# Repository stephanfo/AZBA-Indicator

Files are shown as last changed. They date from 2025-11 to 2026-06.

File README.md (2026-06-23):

# AZBA Status Indicator

A 3D-printable WiFi-connected LED indicator display for real-time monitoring of AZBA (Airspace Restriction Zone) activation status. This project displays the current and upcoming airspace restrictions for a configurable zone using an ESP8266 microcontroller and addressable RGB LEDs.

**Hardware Model:** [AZBA Status Indicator on Printables](https://www.printables.com/model/1487021-azba-status-indicator-3d-printable-display-for-des)

<div align="center">

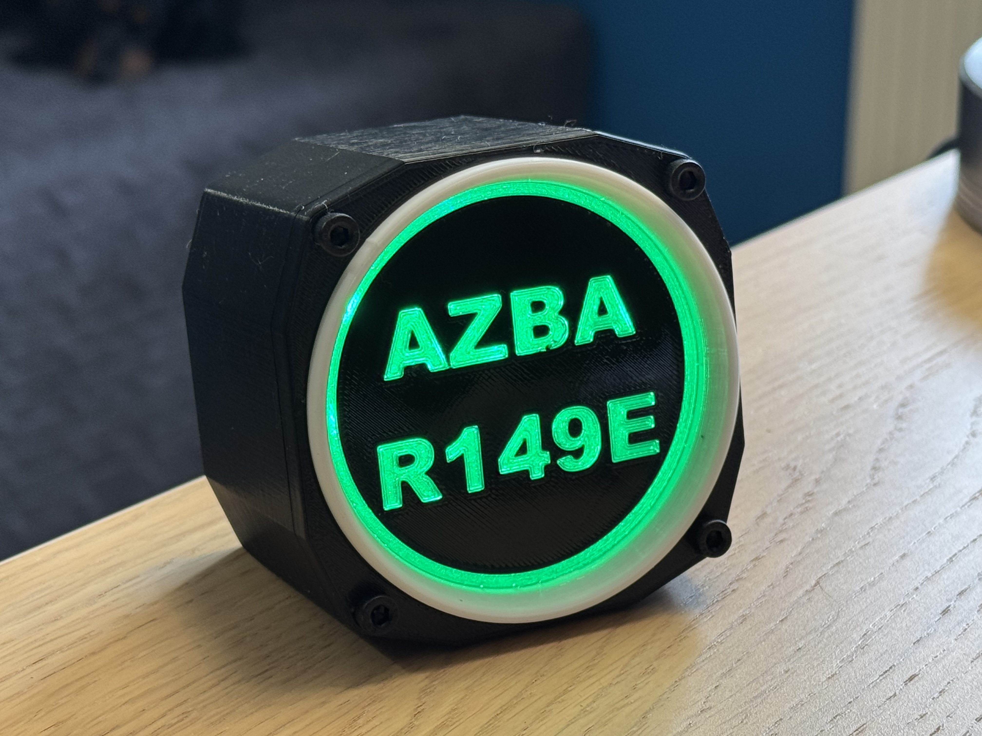
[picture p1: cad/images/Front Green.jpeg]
Front View

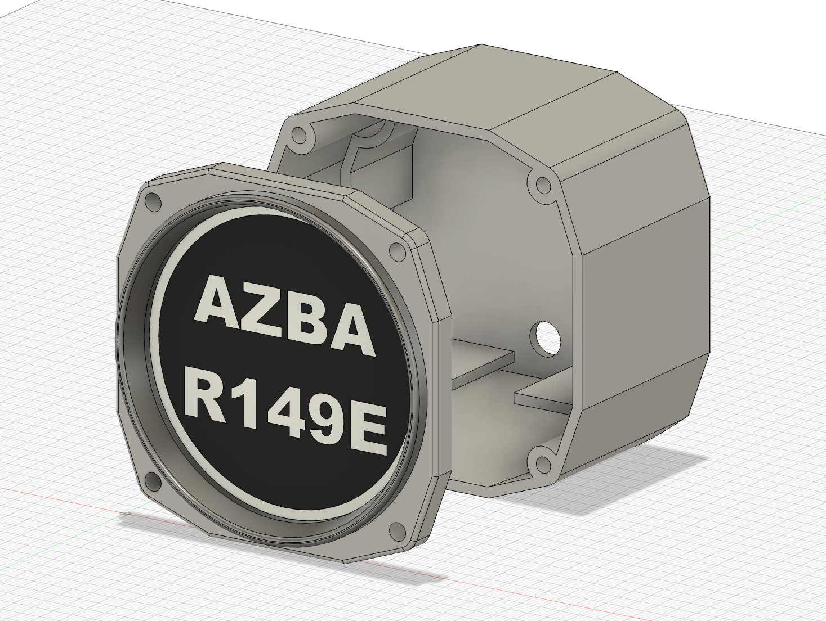
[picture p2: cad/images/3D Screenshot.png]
3D Model

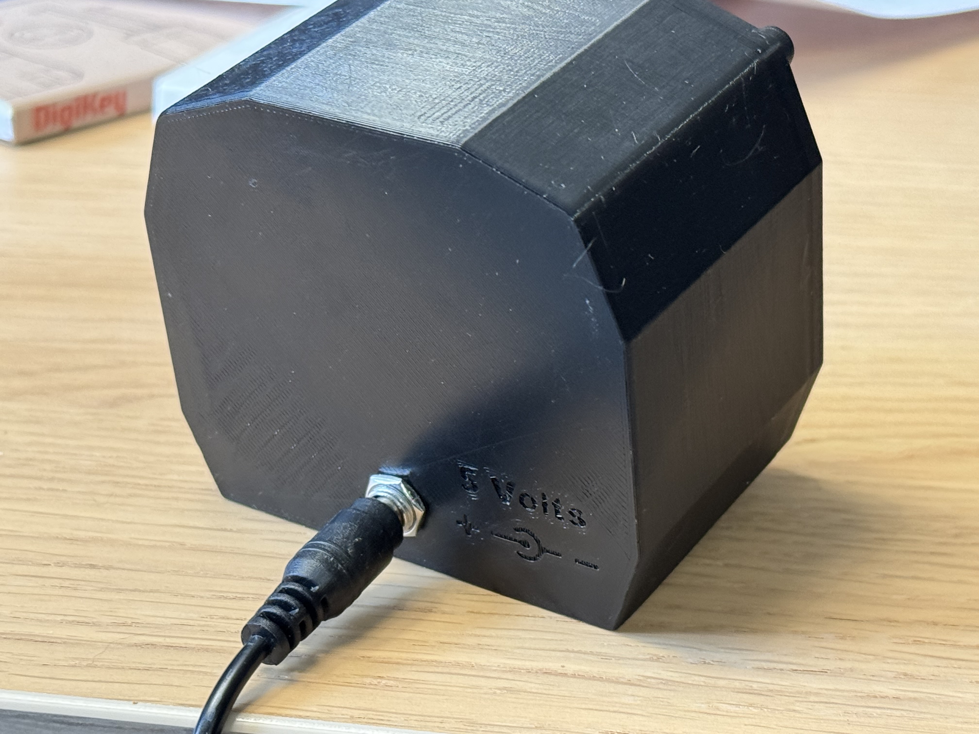
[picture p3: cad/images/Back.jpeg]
Back View

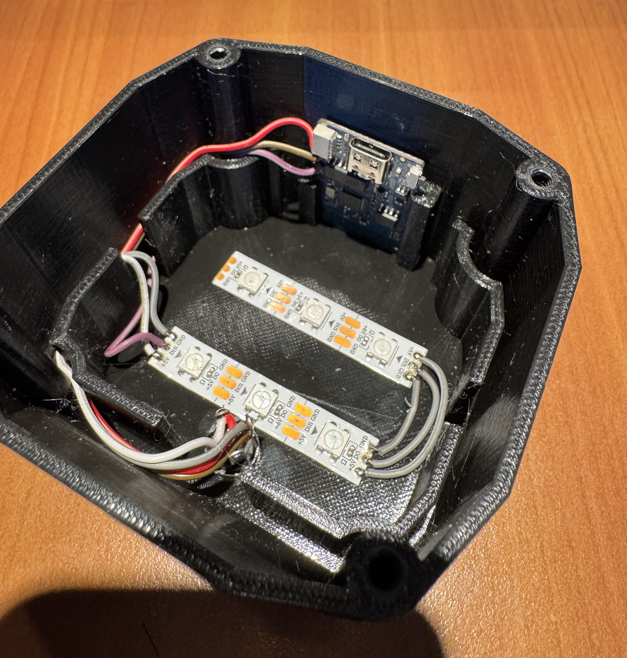
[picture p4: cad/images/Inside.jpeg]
Inside View


</div>

## Features

- **Real-time AZBA Status Display** — Shows if your configured airspace zone is currently active
- **Upcoming Activity Alerts** — Visual indication if the zone will be active within 4 hours
- **LED Status Indicators**
  - 🟢 Green (solid): Zone inactive and not planned to be active
  - 🟡 Yellow (solid): Zone will be active in the future
  - 🟠 Orange (blinking): Zone will be active soon (within 4 hours)
  - 🔴 Red (blinking): Zone active now
  - 🔵 Blue: WiFi connecting
  - ⚪ White: Error or startup
- 🔄 **Automatic Refresh** — Fetches AZBA data every 5 minutes
- 🔁 **Auto-Reboot** — Automatically reboots every 48 hours to prevent memory drift
- 🛡️ **WiFi Resilience** — Automatic retry logic (3 retries with 25-second intervals)
- 🌐 **Static or DHCP IP** — Flexible network configuration

## Hardware Requirements

- **Microcontroller:** Wemos D1 Mini Lite (ESP8266)
- **LEDs:** 6× WS2812B (NeoPixel) addressable RGB LEDs
- **Power Supply:** 5V/1A jack
- **3D Enclosure:** See [Printables model](https://www.printables.com/model/1487021-azba-status-indicator-3d-printable-display-for-des)

## Software Requirements

- **PlatformIO** (recommended) or Arduino IDE
- **Python 3** (optional - for generating secrets from environment variables)
- **PHP 8.0+** with cURL (for the `php/azba.php` backend and its tests; no Composer needed)
- **Dependencies** (auto-installed by PlatformIO):
  - Adafruit NeoPixel library
  - ArduinoJson library

## Quick Start

### 1. Clone the Repository

```bash
git clone https://github.com/stephanfo/AZBA-Indicator.git
cd AZBA-Indicator
```

### 2. Configure Your Secrets

Copy the example secrets file:

```bash
cp src/secrets.example.h src/secrets.h
```

Edit `src/secrets.h` with your WiFi credentials:

```c
const char* ssid     = "Your-WiFi-SSID";
const char* password = "Your-WiFi-Password";
```

**Or** use environment variables for automated generation:

```bash
export SSID="Your-WiFi-SSID"
export PASSWORD="Your-WiFi-Password"
```

### 3. Configure Your AZBA Zone

Edit `src/main.cpp` and change the `ZONE_ID` to your desired zone:

```cpp
const char* ZONE_ID  = "R149E";   // Change to your zone (e.g., R45S3, R142A)
```

Available zones: R45S3, R142A, R45N5.1, R45N4, etc. (see AZBA documentation)

### 4. Build and Upload

```bash
platformio run
platformio run --target upload
```

Or use the pre-configured tasks in VS Code if you have PlatformIO extension installed.

### 5. Monitor Serial Output

```bash
platformio device monitor --baud 115200
```

## Advanced Configuration

### Static IP (Optional)

If you want to use a static IP instead of DHCP, set environment variables before building:

```bash
export SSID="Your-WiFi-SSID"
export PASSWORD="Your-WiFi-Password"
export USE_STATIC_IP=true
export STATIC_IP="192.168.1.50"
export GATEWAY_IP="192.168.1.1"
export SUBNET_MASK="255.255.255.0"
export DNS1_IP="8.8.8.8"
export DNS2_IP="8.8.4.4"
platformio run
```

Then uncomment `#define USE_STATIC_IP` in `src/secrets.h` if not auto-generated.

### Configurable Parameters

Edit the constants in `src/main.cpp`:

- `FETCH_INTERVAL_MS` — Refresh interval (default: 300,000 ms = 5 minutes)
- `REBOOT_INTERVAL_MS` — Auto-reboot interval (default: 172,800,000 ms = 48 hours)
- `FETCH_MAX_RETRIES` — Number of retries on failure (default: 3)
- `FETCH_RETRY_INTERVAL_MS` — Delay between retries (default: 25 seconds)
- `LED_PIN` — GPIO pin for LED strip (default: D4)
- `LED_COUNT` — Number of LEDs (default: 6)

## LED Behavior

### Status Modes

| Mode | LED Color | Behavior | Meaning |
|---|---|---|---|
| `MODE_INACTIVE` | Green | Solid | Zone is inactive |
| `MODE_WILL_BE_ACTIVE_LATER` | Yellow | Solid | Zone will be active, but beyond 4 hours |
| `MODE_WILL_BE_ACTIVE_SOON` | Orange | Blinking | Zone will be active within 4 hours |
| `MODE_ACTIVE_NOW` | Red | Blinking | Zone is active right now |
| `MODE_CONNECTING` | Blue | Solid | WiFi is connecting |
| `MODE_ERROR_OR_STARTUP` | White | Solid | Startup or error condition |

## API Data Source

The device does **not** talk to the SIA directly. It calls a small PHP backend
(`php/azba.php`) that you host on your own server or public endpoint; the
firmware fetches `azba.php?azba=<ZONE_ID>` and reads three booleans per zone
(`is_active_now`, `will_be_active`, `will_be_active_soon`).

The backend is split into two files along a clean reuse boundary:

- **`php/azba_lib.php`** — a self-contained, reusable SIA client. It queries the
  **official SIA JSON API** (the same backend the "AZBA2" web app at
  `https://www.sia.aviation-civile.gouv.fr/azbaEx/` uses), decodes it, and
  validates it (fail-safe guards). It returns the **raw extracted data only** —
  the validity interval and each zone's activation time slots:
  - `…/api/v3/custom/currentDate` — the current validity window
  - `…/api/v3/r_t_b_as?…` — the list of active zones with their UTC time slots
- **`php/azba.php`** — the project-specific request handler. It holds this
  product's application logic: the activity flags (`is_active_now` /
  `will_be_active` / `will_be_active_soon`, with the +5 min anticipation and the
  4-hour window), the `?azba=<ZONE_ID>` filter, the metadata counters, and the
  JSON output contract the firmware expects.

> Historically `azba.php` scraped the HTML of `/schedules`. That page is now a
> JavaScript single-page app with no parseable text, so the scraper broke. The
> backend was rewritten to use the structured JSON API above, which is far more
> robust to wording/markup changes. See [CHANGELOG.md](CHANGELOG.md).

### Reusing the library in another project

`php/azba_lib.php` has no dependencies (no Composer). Copy it in, `require` it,
and call `azba_fetch()` to get the raw SIA data; then apply whatever analysis and
output format your project needs. You only write your own handler — never the
SIA querying/extraction.

```php
require 'azba_lib.php';

try {
    $sia = azba_fetch();
    // $sia = [
    //   'interval' => ['start_utc' => '...Z', 'end_utc' => '...Z'],
    //   'zones'    => [ 'R45S3' => ['activations' => [
    //       ['date' => 'YYYY-MM-DD', 'start_utc' => '...Z', 'end_utc' => '...Z'], ...
    //   ]], ... ],   // only zones active in the current window are present
    // ];

    // ...your project's logic: decide what "active/soon" means, format, etc.
    echo json_encode($sia);
} catch (AzbaFetchException $e) {  // SIA unreachable / auth rejected (HTTP code in getCode())
    // handle network failure
} catch (AzbaDataException $e) {   // SIA responded but the data can't be trusted
    // handle contract change — fail visibly, never assume "inactive"
}
```

See `php/azba.php` for a complete handler that turns this raw data into the
firmware's activity flags + JSON. Its `azba_compute_flags()` / `azba_filter_zone()`
/ `azba_build_metadata()` are examples of the per-project layer you would adapt.

To override the API base or shared secret (e.g. after a SIA rotation) without
editing the file, `define('AZBA_API_BASE', …)` / `define('AZBA_SHARE_SECRET', …)`
before the `require`, or pass `apiBase` / `shareSecret` in the `azba_fetch()`
options array.

### Fail-safe design (important)

A *false "inactive"* is dangerous — it could imply a restricted low-altitude
military zone is clear when it is actually active. So `azba.php` **never returns
a "200 OK" it is not confident in**: on any doubt (auth rejected, unexpected
response shape, stale validity window, unparsable times) it returns an HTTP
error, which the firmware shows as the **white ERROR LED** (a visible fault)
rather than silently signalling "clear" (green).

### Backend maintenance & tests

The data-integrity guards and the time logic are unit-tested. From the repo root:

```bash
php tests/run.php              # offline, deterministic unit tests
AZBA_LIVE=1 php tests/run.php  # also checks the live SIA API contract
```

If the SIA rotates its API again, the live test fails fast and the header of
`php/azba_lib.php` documents how to re-extract the API base / shared secret from
the web app bundle.

## Project Structure

```
.
├── README.md                      # This file
├── CHANGELOG.md                   # Notable changes per version
├── platformio.ini                 # PlatformIO configuration
├── src/
│   ├── main.cpp                   # Main firmware code
│   ├── secrets.example.h          # Template for WiFi credentials & IP config
│   └── secrets.h                  # ⚠️ Local credentials (NOT committed, git-ignored)
├── extra/
│   └── generate_secrets.py        # Script to auto-generate secrets.h from env vars
├── php/
│   ├── azba.php                   # Example request handler (reads ?azba=, outputs JSON)
│   └── azba_lib.php               # Self-contained, reusable SIA client (azba_fetch)
├── tests/
│   ├── run.php                    # Zero-dependency test runner (php tests/run.php)
│   └── fixtures/                  # Captured SIA API responses for offline tests
├── cad/
│   ├── fusion360/                 # 3D CAD files (Fusion 360 project)
│   ├── step/                      # STEP format 3D models
│   └── images/                    # Product photos and 3D renderings
└── .gitignore                     # Git ignore rules (includes secrets, build artifacts)
```

## Building the 3D Enclosure

The 3D printable enclosure is available on Printables:
[AZBA Status Indicator Model](https://www.printables.com/model/1487021-azba-status-indicator-3d-printable-display-for-des)

**Recommended Settings:**
- **Material:** PLA or PETG
- **Layer Height:** 0.2 mm
- **Infill:** 15–20%
- **Support:** Yes (for LED window)
- **Print Time:** ~4–6 hours
- **Filament:** ~40–50 grams

## Troubleshooting

### Device won't connect to WiFi

1. Check credentials in `src/secrets.h`
2. Verify SSID is not hidden
3. Ensure WiFi signal is strong and 2.4GHz available
4. Check serial output for error messages: `platformio device monitor --baud 115200`

### LEDs not lighting up

1. Verify LED_PIN configuration matches your wiring (default: D4)
2. Check power supply (5V, adequate amperage for all LEDs)
3. Verify WS2812B LED strip is properly connected (GND, 5V, Data)
4. Try uploading LED test sketch to verify wiring

### AZBA data not updating

1. Check internet connection: Open serial monitor and look for HTTP errors
2. Verify `ZONE_ID` is valid
3. Ensure backend URL (`URL_BASE`) is accessible
4. If the LED is **white (error)**, the backend returned a non-200 — this is the
   intended fail-safe (never a false "inactive"). Hit `azba.php` directly in a
   browser to read the JSON `error` message.
5. Run `AZBA_LIVE=1 php tests/run.php` on the server: if the live test fails, the
   SIA API contract changed and `php/azba.php` needs updating (the file header
   documents how to re-extract the API base / shared secret).

### Device reboots frequently

1. Check power supply stability (use good quality PSU)
2. Verify antenna position on Wemos D1 Mini (avoid metal surfaces around)
3. Increase `REBOOT_INTERVAL_MS` if reboots are too frequent

## Contributing

Contributions are welcome! Please:

1. Fork the repository
2. Create a feature branch (`git checkout -b feature/your-feature`)
3. Make your changes
4. Test thoroughly on hardware
5. Commit with clear messages
6. Push to your fork
7. Open a Pull Request

## License

This project is licensed under the MIT License — see LICENSE file for details.

## Support & Feedback

- **Issues:** [GitHub Issues](https://github.com/stephanfo/AZBA-Indicator/issues)
- **Printables Model Comments:** [Printables Discussion](https://www.printables.com/model/1487021-azba-status-indicator-3d-printable-display-for-des)

## Acknowledgments

- [Adafruit NeoPixel Library](https://github.com/adafruit/Adafruit_NeoPixel)
- [ArduinoJson Library](https://github.com/bblanchon/ArduinoJson)
- [PlatformIO](https://platformio.org/)
- SIA (Service de l'Information Aéronautique) for AZBA data
- Printables community for hardware feedback

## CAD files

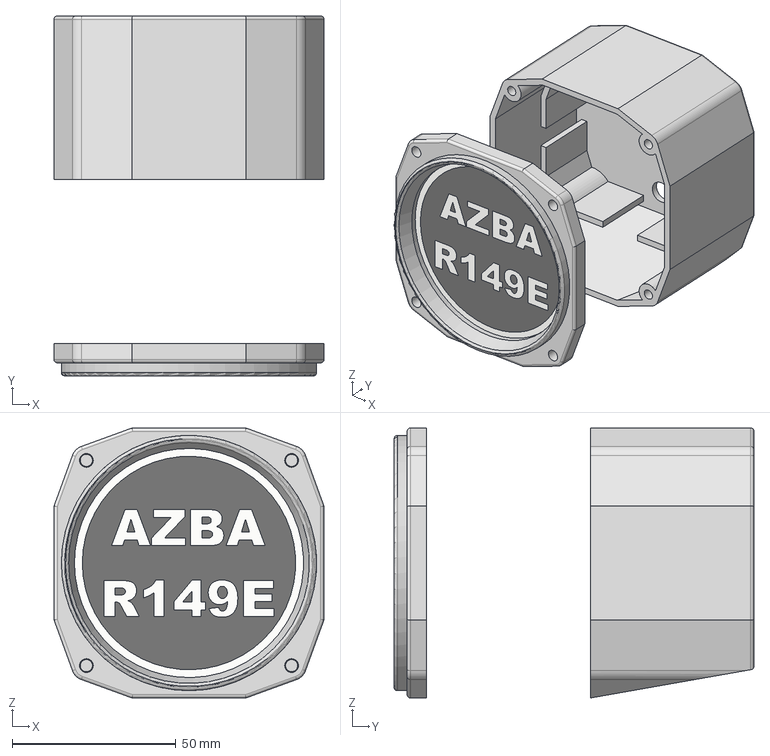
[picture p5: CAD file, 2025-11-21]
cad/step/AZBA R149 Indicator.step
82.5 x 110.0 x 82.5 mm

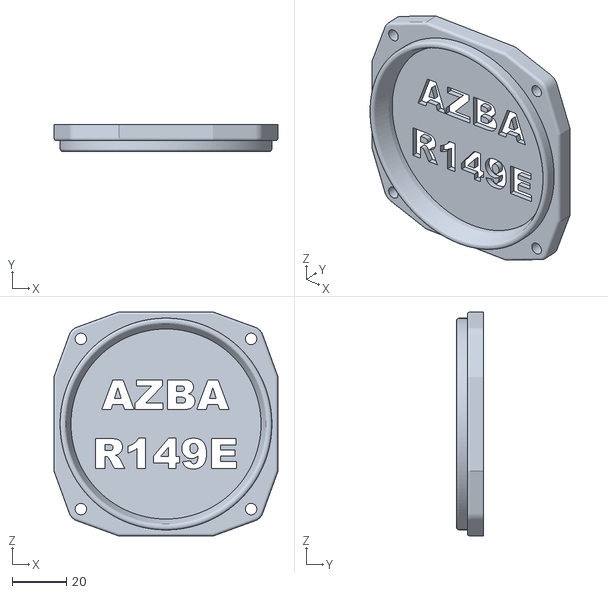
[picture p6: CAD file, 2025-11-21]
cad/stl/Front - Monochrome no MMU.stl
82.5 x 10.0 x 82.5

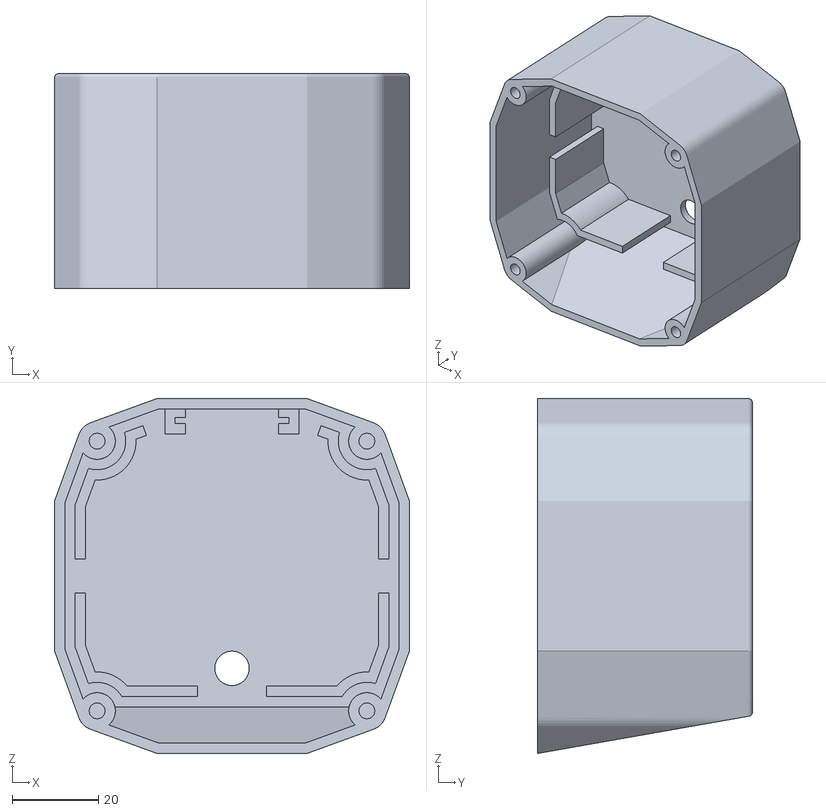
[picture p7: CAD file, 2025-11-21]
cad/stl/Back Case.stl
82.5 x 50.0 x 82.5

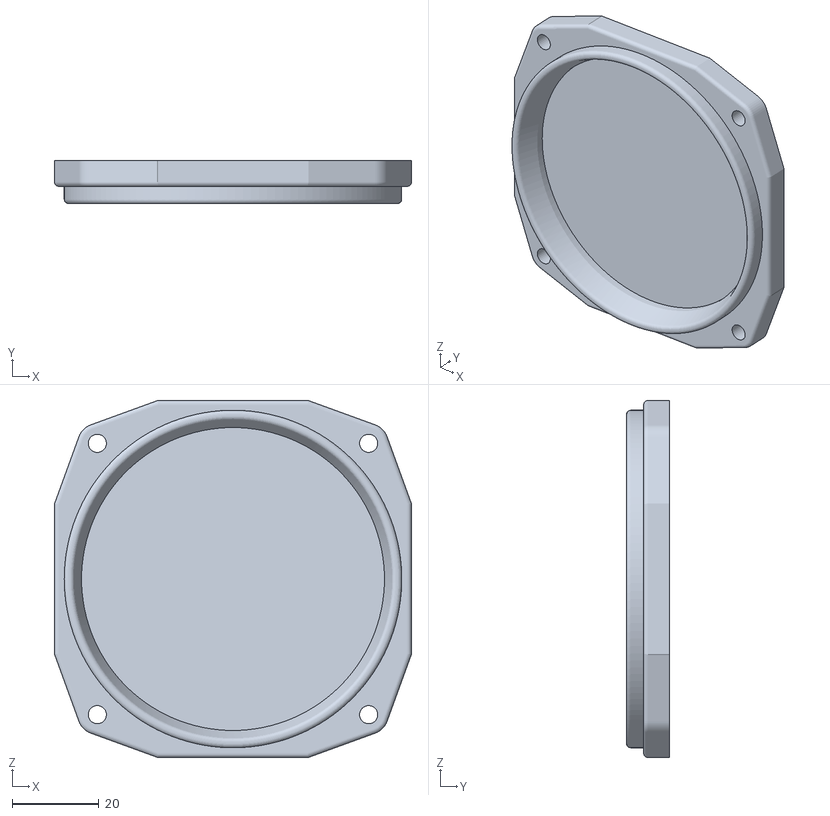
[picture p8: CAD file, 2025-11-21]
cad/stl/Front - MMU2S.stl
82.5 x 10.0 x 82.5

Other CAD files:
cad/fusion360/AZBA R149 Indicator.f3d

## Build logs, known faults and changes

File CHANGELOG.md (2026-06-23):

# Changelog

All notable changes to this project are documented here.

The format is based on [Keep a Changelog](https://keepachangelog.com/en/1.1.0/).
This project does not yet use formal version tags; entries are grouped by date.

## [Unreleased]

### Changed
- **`php/azba.php` rewritten to use the official SIA JSON API.** The old version
  scraped the HTML of `/schedules` and searched for the text
  `"Liste des zones activées"`. The SIA replaced that page with a JavaScript
  single-page app ("AZBA2"), so the text disappeared and the script failed with
  `Bloc "Liste des zones activées" introuvable`. It now queries the structured
  endpoints the web app itself uses (`/api/v3/custom/currentDate` and
  `/api/v3/r_t_b_as`), which are immune to wording/markup changes. The JSON
  output contract is unchanged, so **no firmware change is required**.
- Split the backend into `php/azba.php` (thin entry: network + request/response)
  and `php/azba_lib.php` (pure, testable logic) so the safety guards and time
  math can be unit-tested deterministically. Output is byte-for-byte identical.
- **`php/azba_lib.php` is now a self-contained, reusable SIA library** with a
  clean boundary: it does the SIA querying + decoding + extraction only, exposed
  as a single `azba_fetch()` call returning the **raw data**
  (`['interval' => …, 'zones' => [ 'R45S3' => ['activations' => […]], … ]]`).
  All product-specific analysis — the activity flags (`is_active_now` /
  `will_be_active` / `will_be_active_soon`, the +5 min anticipation and 4-hour
  window), the `?azba=` filter, and the metadata counters — moved **into**
  `php/azba.php`, which is now the swappable request handler. Other projects copy
  `azba_lib.php` (no Composer), call `azba_fetch()`, and apply their own logic.
  The HTTP transport is injectable (`$options['http']`) so the full pipeline is
  testable offline, and the API base / shared secret are overridable via
  `define()` or `$options`. Firmware JSON output remains byte-for-byte identical.
- Errors now use a typed hierarchy: `AzbaException` (base), `AzbaFetchException`
  (network / HTTP / auth, with the HTTP status in `getCode()`), and
  `AzbaDataException` (untrusted data). Callers catch `AzbaException` to handle
  all failures and map them to their own response.

### Added
- **Fail-safe data guards.** A false "inactive" is dangerous (it could imply an
  active restricted zone is clear). The backend now returns a non-200 — surfaced
  as the firmware's white ERROR LED — on any untrusted condition: rejected auth,
  unexpected response shape, missing/empty time slots, unparsable times, or a
  stale/inconsistent validity window. It never emits a "200 OK" it isn't
  confident in.
- Single retry on transient 5xx / network errors when fetching active zones.
- **Zero-dependency PHP test battery** (`tests/run.php`, no Composer/PHPUnit):
  covers every fail-safe guard, the validity-window freshness checks, the
  `is_active_now` / `will_be_active` / `will_be_active_soon` boundary math, the
  zone filter, and metadata counters. An opt-in live mode
  (`AZBA_LIVE=1 php tests/run.php`) re-checks the upstream SIA contract so an API
  change is caught early. Offline fixtures live in `tests/fixtures/`.
- Documentation in the `php/azba.php` header explaining the API, the `AUTH`
  header scheme, and how to re-extract the API base / shared secret from the SIA
  web app bundle if the SIA rotates them.

### Fixed
- Indicator no longer fails permanently after the SIA AZBA page redesign.

## [2026-06-23] — Documentation & configuration

### Changed
- Improved LED state descriptions, added the AZBA zone configuration to
  `secrets.example.h`, and updated the base URL.

## [2025-11-22]

### Changed
- `refreshCount` starts at 1 and is incremented even when no AZBA zones are
  found; added the "inside" product image.

## [2025-11-21] — Initial release

### Added
- ESP8266 firmware driving WS2812B LEDs to show AZBA zone status (active now /
  soon / later / inactive), with WiFi resilience and periodic auto-reboot.
- PHP backend, 3D-printable enclosure, and secrets tooling. Default zone aligned
  to `R149E` to match the reference hardware.

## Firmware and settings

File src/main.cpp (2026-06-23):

#include <ESP8266WiFi.h>
#include <ESP8266HTTPClient.h>

#include <Adafruit_NeoPixel.h>
#include <ArduinoJson.h>

#include "secrets.h" // WiFi credentials and optional static IP configuration

// ------------ CONFIG LEDS ------------
#define LED_PIN    D4
#define LED_COUNT  6

Adafruit_NeoPixel strip(LED_COUNT, LED_PIN, NEO_GRB + NEO_KHZ800);

enum Mode {
  MODE_CONNECTING,            // Blue solid (WiFi connecting)
  MODE_ERROR_OR_STARTUP,      // White solid (error/startup)
  MODE_ACTIVE_NOW,            // Red blinking (active now)
  MODE_WILL_BE_ACTIVE_SOON,   // Orange blinking (active soon, within 4h)
  MODE_WILL_BE_ACTIVE_LATER,  // Yellow solid (active later, beyond 4h)
  MODE_INACTIVE               // Green solid (inactive)
};

Mode currentMode = MODE_ERROR_OR_STARTUP;

// --- Intervals and parameters ---
// Interval between normal refreshes (5 minutes)
const unsigned long FETCH_INTERVAL_MS = 300000UL;      // 5 minutes
// Automatic reboot every 48 hours to avoid memory leaks/drift
const unsigned long REBOOT_INTERVAL_MS = 172800000UL;  // 48 hours in milliseconds
// Retry parameters: number of retries and delay between them
// (e.g. FETCH_MAX_RETRIES = 2 => initial attempt + 2 retries)
const int FETCH_MAX_RETRIES = 3;                       // number of retries (0 = no retry)
const unsigned long FETCH_RETRY_INTERVAL_MS = 25000UL; // 25 seconds between retries

// Timestamps and counters
unsigned long lastFetchMs = 0;   // timestamp of last fetch (millis())
unsigned long startupTimeMs = 0; // application startup timestamp
// Number of refresh cycles performed (incremented before each fetch)
// This counter is sent to the server for diagnostics (`refresh_count`)
unsigned long refreshCount = 1; // number of refreshes (5-minute cycles)
// Diagnostics counters
unsigned long totalAttempts = 0;          // total HTTP attempts across retries
unsigned long totalSuccessfulFetches = 0; // total successful fetches
unsigned int consecutiveFailures = 0;     // consecutive failed fetch cycles

// JSON buffer size (changeable)
#define JSON_BUF_SIZE 2048

// ------------ LED FUNCTIONS ------------
void setAllPixels(uint32_t color) {
  for (int i = 0; i < LED_COUNT; i++) {
    strip.setPixelColor(i, color);
  }
}

void updateLeds() {
  uint32_t color = 0;
  bool blinking = false;

  switch (currentMode) {
    case MODE_CONNECTING:
      color = strip.Color(0, 0, 255);      // Blue
      blinking = false;
      break;
    case MODE_ACTIVE_NOW:
      color = strip.Color(255, 0, 0);      // Red
      blinking = true;
      break;
    case MODE_WILL_BE_ACTIVE_SOON:
      color = strip.Color(255, 60, 0);     // Orange blinking (within 4h)
      blinking = true;
      break;
    case MODE_WILL_BE_ACTIVE_LATER:
      color = strip.Color(255, 120, 0);    // Yellow solid (beyond 4h)
      blinking = false;
      break;
    case MODE_INACTIVE:
      color = strip.Color(0, 255, 0);      // Green
      blinking = false;
      break;
    case MODE_ERROR_OR_STARTUP:
    default:
      color = strip.Color(255, 255, 255);  // White
      blinking = false;
      break;
  }

  if (blinking) {
    bool on = ((millis() / 500) % 2) == 0; // 500 ms
    if (on) setAllPixels(color);
    else    setAllPixels(0);
  } else {
    setAllPixels(color);
  }

  strip.show();
}

// ------------ HTTP + JSON ------------
void softReboot() {
  Serial.println(F("\n\n=== SYSTEM REBOOT ===\n"));
  delay(1000);
  ESP.restart();
}

void reconnectWiFi() {
  // Simple WiFi reconnect attempt: switch to STA mode and wait
  // a few seconds (loop with delays) while showing blue LEDs.
  Serial.println(F("Attempting WiFi reconnect..."));
  currentMode = MODE_CONNECTING;  // Switch to blue
  
  WiFi.mode(WIFI_STA);
  
  #ifdef USE_STATIC_IP
    WiFi.config(staticIP, gateway, subnet, dns1, dns2);
  #endif
  
  WiFi.begin(ssid, password);

  int retry = 0;
  while (WiFi.status() != WL_CONNECTED && retry < 60) {
    delay(500);
    Serial.print(".");
    updateLeds();  // Update LEDs to blue during reconnect
    retry++;
  }
  Serial.println();

  if (WiFi.status() == WL_CONNECTED) {
    Serial.print(F("Reconnected, IP: "));
    Serial.println(WiFi.localIP());
    delay(2000);  // Allow connection to stabilize
  } else {
    Serial.println(F("WiFi reconnect failed"));
    currentMode = MODE_ERROR_OR_STARTUP;
  }
}

// fetchStatus()
// - checks WiFi connection and attempts reconnect if necessary
  // - builds the request URL including two additional query parameters:
//     `refresh_count`: number of successful refresh cycles already performed (does NOT include current)
//     `attempt_count`: number of the current attempt (1..N)
// - performs the HTTP request and parses the returned JSON
// - maps JSON fields to `currentMode` to drive the LEDs
// - on failure, retry up to `FETCH_MAX_RETRIES` times with delay

void fetchStatus() {
  if (WiFi.status() != WL_CONNECTED) {
    Serial.println(F("WiFi not connected -> reconnecting"));
    reconnectWiFi();
    
    // If still not connected after attempt, exit
    if (WiFi.status() != WL_CONNECTED) {
      Serial.println(F("WiFi still not connected"));
      currentMode = MODE_ERROR_OR_STARTUP;
      return;
    }
  }

  // The URL is built for each attempt to include
  // `refresh_count` and `attempt_count` as query parameters.

  WiFiClient client;
  client.setTimeout(10000);         // 10 seconds read timeout

  HTTPClient http;
  http.setTimeout(10000);           // 10 seconds timeout

  bool success = false;
  // Retry loop: perform the initial attempt (attempt=0)
  // then up to FETCH_MAX_RETRIES retries (attempt = 1..FETCH_MAX_RETRIES)
  for (int attempt = 0; attempt <= FETCH_MAX_RETRIES; attempt++) {
    Serial.printf("Attempt %d/%d\n", attempt + 1, FETCH_MAX_RETRIES + 1);

    // Count this HTTP attempt for diagnostics
    totalAttempts++;

    // Build URL in a stack buffer to avoid String heap fragmentation on ESP8266
    char fullUrl[256];
    int len = snprintf(fullUrl, sizeof(fullUrl), "%s?azba=%s&refresh_count=%lu&attempt_count=%d",
                       URL_BASE, ZONE_ID, refreshCount, attempt + 1);
    if (len < 0 || len >= (int)sizeof(fullUrl)) {
      Serial.println(F("Warning: URL truncated"));
    }
    Serial.print(F("Request URL: "));
    Serial.println(fullUrl);

    if (!http.begin(client, fullUrl)) {
      // Error initializing HTTP request (e.g. bad URL, socket)
      Serial.println(F("http.begin() error"));
      http.end();
      client.stop();
      
    } else {
      int httpCode = http.GET();
      // Check returned HTTP status code
      if (httpCode != HTTP_CODE_OK) {
        Serial.printf("HTTP error: %d\n", httpCode);
        http.end();
        client.stop();
        
      } else {
        String payload = http.getString();
        http.end();
        client.stop();

        StaticJsonDocument<JSON_BUF_SIZE> doc;
        DeserializationError error = deserializeJson(doc, payload);

        // Parse JSON
        if (error) {
          Serial.print(F("JSON parse error: "));
          Serial.println(error.c_str());
          
        } else if (!doc.containsKey("zones")) {
          Serial.println(F("JSON does not contain 'zones'"));
          
        } else {
          JsonObject zones = doc["zones"];

          if (!zones.containsKey(ZONE_ID)) {
            Serial.print(F("JSON.zones does not contain '"));
            Serial.print(ZONE_ID);
            Serial.println(F("'"));
            currentMode = MODE_INACTIVE;
            success = true;
            refreshCount++; // Zone not found still counts as a valid refresh cycle
            break;
          }

          JsonObject z = zones[ZONE_ID];

          bool isActiveNow       = z["is_active_now"]       | false;
          bool willBeActive      = z["will_be_active"]      | false;
          bool willBeActiveSoon  = z["will_be_active_soon"] | false;

          Serial.printf("%s.is_active_now       = %s\n", ZONE_ID, isActiveNow ? "true" : "false");
          Serial.printf("%s.will_be_active      = %s\n", ZONE_ID, willBeActive ? "true" : "false");
          Serial.printf("%s.will_be_active_soon = %s\n", ZONE_ID, willBeActiveSoon ? "true" : "false");

          if (isActiveNow) {
            currentMode = MODE_ACTIVE_NOW;
          } else if (willBeActiveSoon) {
            currentMode = MODE_WILL_BE_ACTIVE_SOON;
          } else if (willBeActive) {
            currentMode = MODE_WILL_BE_ACTIVE_LATER;
          } else {
            currentMode = MODE_INACTIVE;
          }

          // Mark success: update counters
          success = true;
          refreshCount++; // Increment after successfully parsing the zone data
          totalSuccessfulFetches++;
          consecutiveFailures = 0;
          Serial.printf("Fetch successful (total successful: %lu)\n", totalSuccessfulFetches);
          break;
        }
      }
    }

    // If retries remain, optionally log the failed attempt and wait while updating LEDs
    if (attempt < FETCH_MAX_RETRIES) {
      if (!success) {
        Serial.printf("Attempt %d failed, will retry... (totalAttempts=%lu)\n", attempt + 1, totalAttempts);
      }
      Serial.printf("Waiting %lu ms before retry %d/%d\n", FETCH_RETRY_INTERVAL_MS, attempt + 2, FETCH_MAX_RETRIES + 1);
      currentMode = MODE_ERROR_OR_STARTUP; // keep error LED during wait
      unsigned long waitStart = millis();
      while (millis() - waitStart < FETCH_RETRY_INTERVAL_MS) {
        updateLeds();
        delay(200);
      }
    }

  }

  if (!success) {
    consecutiveFailures++;
    Serial.printf("Failed after retries, set to ERROR (consecutive failures=%u)\n", consecutiveFailures);
    currentMode = MODE_ERROR_OR_STARTUP;
  }
}

// ------------ SETUP & LOOP ------------
void setup() {
  Serial.begin(115200);
  delay(100);

  strip.begin();
  strip.show();
  currentMode = MODE_CONNECTING;  // Blue while connecting
  updateLeds();

  Serial.printf("Connecting to WiFi: %s\n", ssid);
  WiFi.mode(WIFI_STA);
  
  #ifdef USE_STATIC_IP
    Serial.println(F("Static IP configuration..."));
    WiFi.config(staticIP, gateway, subnet, dns1, dns2);
  #endif
  
  WiFi.begin(ssid, password);

  int retry = 0;
  while (WiFi.status() != WL_CONNECTED && retry < 60) {
    delay(500);
    Serial.print(".");
    retry++;
  }
  Serial.println();

  if (WiFi.status() == WL_CONNECTED) {
    Serial.print(F("Reconnected, IP: "));
    Serial.println(WiFi.localIP());
    delay(2000);  // Allow WiFi to stabilize
    fetchStatus(); // first request
  } else {
    Serial.println(F("WiFi connection failed -> WHITE (ERROR)"));
    currentMode = MODE_ERROR_OR_STARTUP;
  }

  lastFetchMs = millis();
  startupTimeMs = millis();  // Record startup time
}

void loop() {
  updateLeds();

  unsigned long now = millis();
  
  // Check reboot every 48 hours
  if (now - startupTimeMs >= REBOOT_INTERVAL_MS) {
    Serial.println(F("System reboot every 48 hours"));
    softReboot();
  }

  if (now - lastFetchMs >= FETCH_INTERVAL_MS) {
    lastFetchMs = now;
    fetchStatus();
  }

  delay(10);
}

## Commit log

2025-11-21 Initial commit: AZBA Indicator project
    [AZBA R149 Indicator.f3d, AZBA R149 Indicator.step, Back Case.stl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]
2026-06-23 Mise à jour de la documentation et des configurations pour l'indicateur AZBA : amélioration des descriptions des états LED, ajout de la configuration de la zone AZBA dans le fichier secrets.example.h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
2026-06-23 Rewrite AZBA backend to use the official SIA JSON API
    The old php/azba.php scraped the HTML of /schedules for the text block
    "Liste des zones activées". The SIA replaced that page with a JavaScript
    single-page app ("AZBA2"), so the text disappeared and the endpoint failed
    with `Bloc "Liste des zones activées" introuvable`.
    It now queries the structured JSON API the web app itself uses
    (/api/v3/custom/currentDate + /api/v3/r_t_b_as), which is immune to
    wording/markup changes. The firmware JSON contract is unchanged, so no
    firmware change is required (verified byte-for-byte).
    Structure / reuse:
    - php/azba_lib.php: self-contained, reusable SIA client (no Composer).
    azba_fetch() does the q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
2026-10-21 Configure the indicator at runtime and install it from the browser
    - Captive portal (WiFiManager) on first boot for WiFi, AZBA zone and
    backend URL, stored in LittleFS; reopened by a double restart or after
    repeated WiFi failures. Purple slow blinking = portal open.
    - lib/AzbaConfig normalizes the zone like the backend's keys (a lower-case
    zone used to stay green forever), with native unit tests.
    - HTTPS backends and HTTP redirects supported.
    - Compile-time secrets and static IP removed.
    - site/: French/English presentation page (azba.ratelet.fr) with an
    ESP Web Tools installer; site/build.sh and a GitHub Pages workflow build,
    test and publish the firmware, manifest and backend zip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
2026-10-21 Catch any Throwable when parsing SIA dates
    Some PHP builds (the GitHub Ubuntu runner's) throw an Error, not an
    Exception, on a malformed date string, so the guards let it escape instead
    of raising AzbaDataException. The test runner now prints the message of an
    unexpected throwable, and the workflow logs the PHP version.
